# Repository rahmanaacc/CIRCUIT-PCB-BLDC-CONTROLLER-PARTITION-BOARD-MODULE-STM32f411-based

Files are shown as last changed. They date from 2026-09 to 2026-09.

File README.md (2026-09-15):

# Modular BLDC Motor Controller Partition Board (STM32F411CEU6 Based)

Projek Capstone ini berfokus pada perancangan hardware modul *controller* motor BLDC (Brushless DC) berbasis mikrokontroler **STM32F411CEU6** menggunakan metode kontrol **6-step commutation (trapezoidal control)**. 

Arsitektur hardware dirancang secara modular (*partition board*) dengan memisahkan domain sinyal kendali, *gate driver*, dan tingkat daya (*inverter stage*). Pemisahan topologi ini bertujuan untuk meminimalkan *noise* switching (EMI), mengoptimalkan manajemen termal, serta mempermudah proses pengujian dan *troubleshooting* secara independen pada tiap modul.

---

## Modul Hardware Utama

Repository ini terdiri dari tiga modul papan terpisah (*partition boards*):

1. **Control-MCU Module (`Control-MCU With Voltage Drop Detector 0,5mm`)**
   * Modul pemroses utama berbasis mikrokontroler **STM32F411CEU6**.
   * Dilengkapi rangkaian *Voltage Drop Detector* dengan lebar jalur *trace* teroptimasi 0,5 mm untuk menjaga integritas sinyal dan stabilitas tegangan referensi MCU.
   * Berfungsi mengolah algoritma **6-step commutation**, membaca sinyal *feedback* posisi rotor, dan menghasilkan sinyal PWM transmisi ke *gate driver*.

2. **Driver & Switching Optimization Circuit (`DRIVER and SWITCHING OPTIMIZATION CIRCUIT REV 2`)**
   * Modul perantara *gate driver* yang mengisolasi sinyal logika kendali level rendah dari tegangan tinggi *inverter*.
   * Mengintegrasikan rangkaian optimasi *switching* untuk mempercepat *rise/fall time* MOSFET, mengurangi *switching loss*, dan mencegah kondisi *cross-conduction* (*shoot-through*).

3. **Inverter Circuit (`INVERTER CIRCUIT REV 2 FIX`)**
   * Modul tingkat daya (*power stage*) berupa jembatan tiga fasa (*three-phase bridge inverter*).
   * Didesain untuk menangani arus tinggi dengan penataan jalur *copper pour* teroptimasi dan konektivitas daya fasa motor yang andal.

---

## Struktur Repository

```text
CIRCUIT-PCB-BLDC-CONTROLLER-PARTITION-BOARD-MODULE-STM32f411-based/
│
├── Control-MCU With Voltage Drop Detector 0,5mm/
│   ├── Control-MCU.kicad_sch          # Skematik KiCad Modul MCU
│   ├── Control-MCU.kicad_pcb          # Layout PCB Modul MCU
│   └── Control-MCU.kicad_pro          # Berkas Proyek KiCad Modul MCU
│
├── DRIVER and SWITCHING OPTIMIZATION CIRCUIT REV 2/
│   ├── DRIVER and SWITCHING OPTIMIZATION CIRCUIT.kicad_sch
│   ├── DRIVER and SWITCHING OPTIMIZATION CIRCUIT.kicad_pcb
│   └── DRIVER and SWITCHING OPTIMIZATION CIRCUIT.kicad_pro
│
├── INVERTER CIRCUIT REV 2 FIX/
│   ├── INVERTER CIRCUIT REV 2 FIX.kicad_sch
│   ├── INVERTER CIRCUIT REV 2 FIX.kicad_pcb
│   └── INVERTER CIRCUIT REV 2 FIX.kicad_pro
│
└── README.md

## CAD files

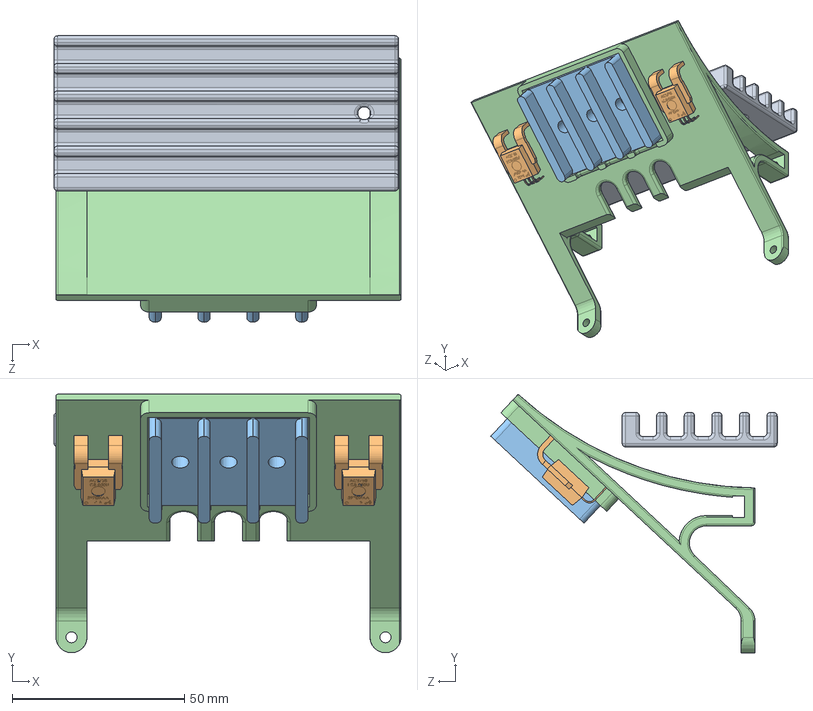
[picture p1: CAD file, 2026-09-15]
INVERTER CIRCUIT REV 2 FIX/mount current sensor.SLDASM
100.7 x 75.0 x 83.1 mm
E bike Connector
ACS758.step x 2
Part1^heatsink

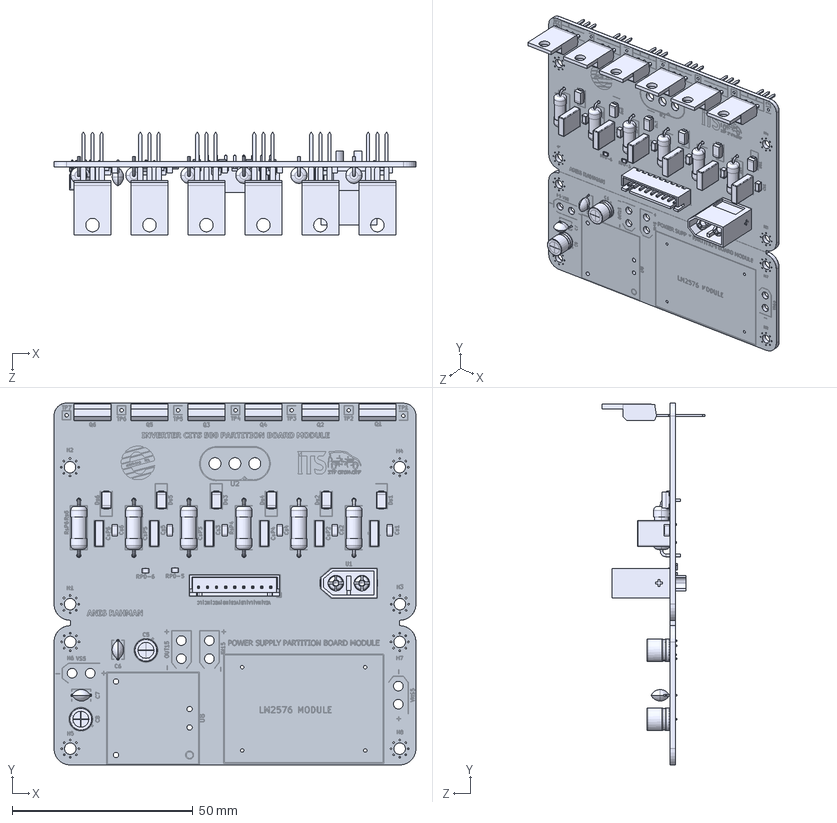
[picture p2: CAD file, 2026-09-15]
INVERTER CIRCUIT REV 2 FIX/INVERTER CIRCUIT REV 2 FIX 2.STEP
100.0 x 100.0 x 28.5 mm
C_Rect_L7.2mm_W2.5mm_P5.00mm_FKS2_FKP2_MKS2_MKP2.step x 6
D_SMA.step x 6
R_1206_3216Metric.step x 6
CP_Radial_D6.3mm_P2.50mm.step x 2
C_1206_3216Metric.step x 6
TO-220-3_Vertical.step x 6
R_Axial_DIN0414_L11.9mm_D4.5mm_P15.24mm_Horizontal.step x 6
C_Disc_D5.1mm_W3.2mm_P5.00mm.step x 2
JST_XH_B9B-XH-A_1x09_P2.50mm_Vertical.step
R_0805_2012Metric.step x 6
INVERTER CIRCUIT REV 2 FIX_soldermask.step
AMASS_XT60-M_1x02_P7.2mm_Vertical.step
INVERTER CIRCUIT REV 2 FIX_silkscreen.step
INVERTER CIRCUIT REV 2 FIX_silkscreen-0.step
INVERTER CIRCUIT REV 2 FIX_soldermask-1.step
INVERTER CIRCUIT REV 2 FIX_PCB.step

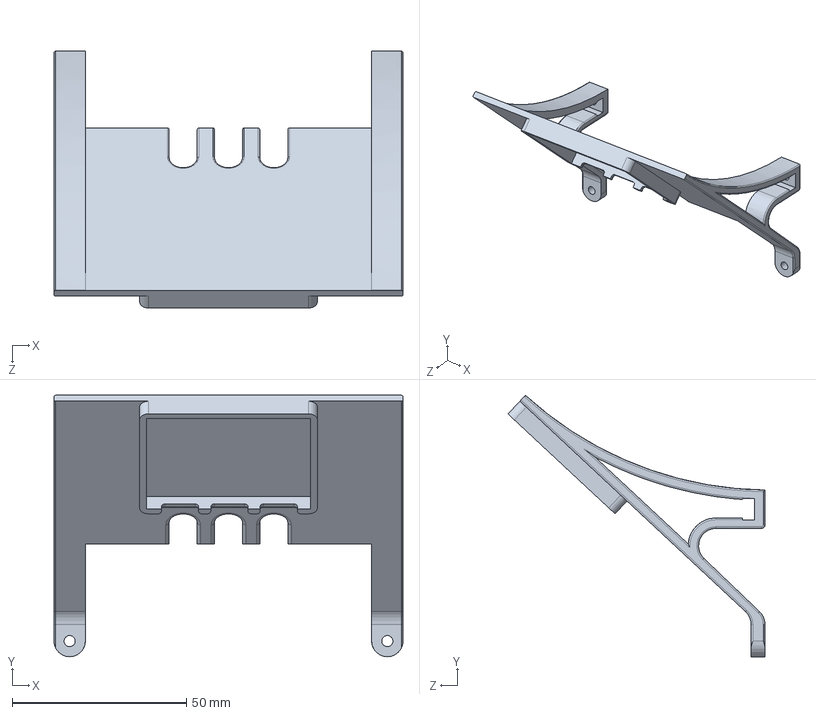
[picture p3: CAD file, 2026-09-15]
INVERTER CIRCUIT REV 2 FIX/Part1.SLDPRT
100.1 x 75.0 x 73.7 mm

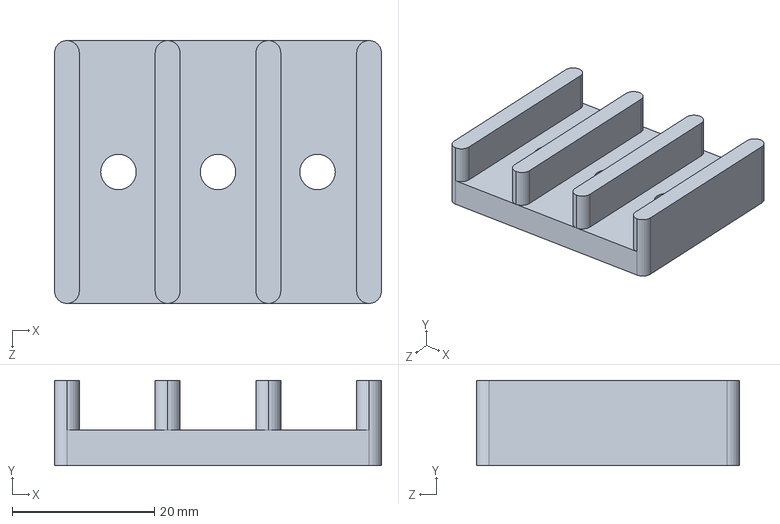
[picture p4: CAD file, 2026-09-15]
INVERTER CIRCUIT REV 2 FIX/E bike Connector.SLDPRT
46.0 x 12.0 x 37.0 mm

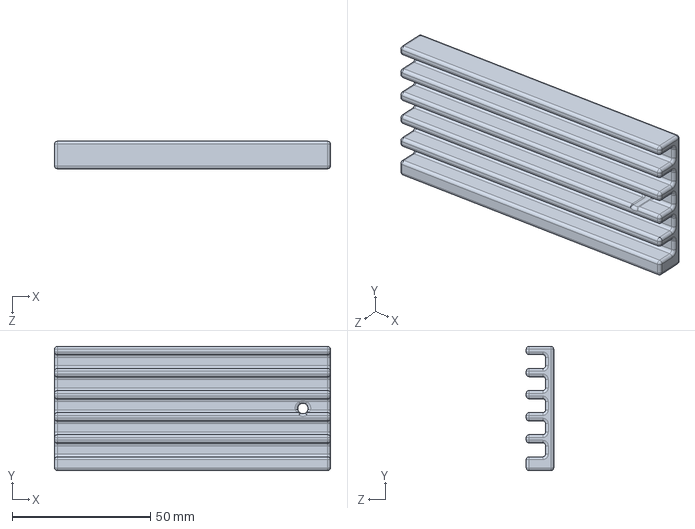
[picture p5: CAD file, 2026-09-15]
INVERTER CIRCUIT REV 2 FIX/Part1^heatsink.SLDPRT
100.0 x 45.0 x 10.0 mm

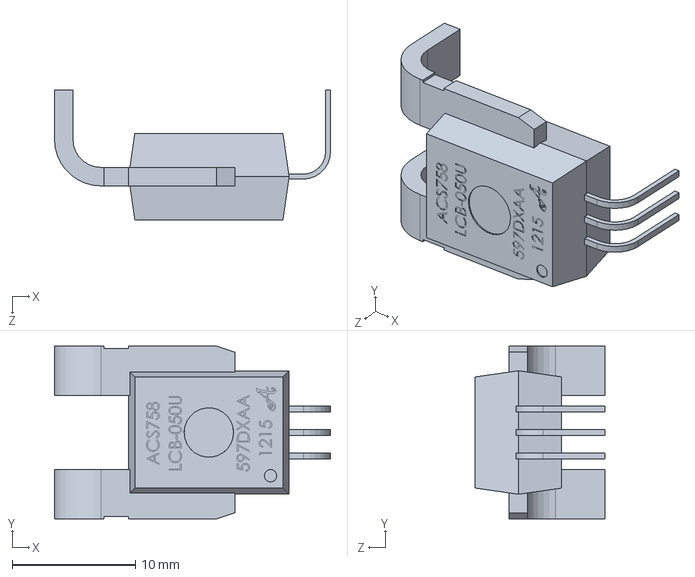
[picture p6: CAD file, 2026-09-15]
INVERTER CIRCUIT REV 2 FIX/ACS758.step.SLDPRT
22.4 x 14.0 x 10.5 mm

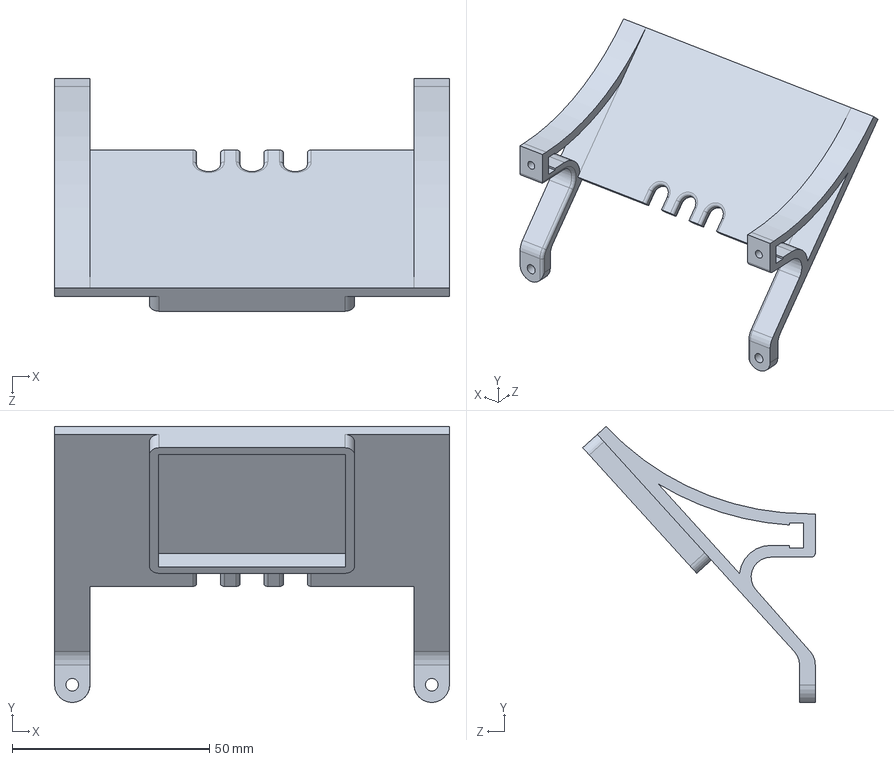
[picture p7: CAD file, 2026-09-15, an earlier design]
INVERTER CIRCUIT REV 2 FIX/Part1 - Copy.SLDPRT
100.1 x 69.9 x 58.9 mm

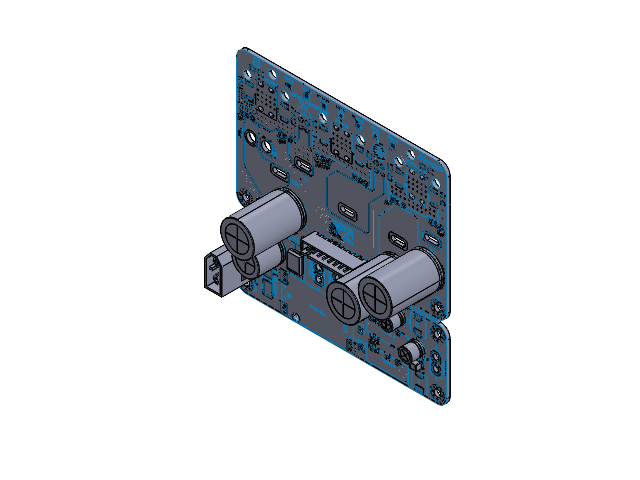
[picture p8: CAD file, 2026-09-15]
INVERTER CIRCUIT REV 2 FIX/INVERTER PARTITION BOARD REV4 STP FINAL CETAK solid.SLDASM
C_Radial_D16.0mm_H25.0mm_P7.50mm.step.STEP x 3
C_0805_2012Metric.step.STEP x 3
R_0603_1608Metric.step.STEP x 6
CP_Radial_D6.3mm_P2.50mm.step.STEP x 2
JST_XH_B9B-XH-A_1x09_P2.50mm_Vertical.step.STEP
AMASS_XT60-M_1x02_P7.2mm_Vertical.step.STEP
D_SMC.step.STEP
C_1210_3225Metric.step.STEP
CP_Radial_D13.0mm_P5.00mm.step.STEP
INVERTER PARTITION BOARD REV3_copper.step.STEP
INVERTER PARTITION BOARD REV3_silkscreen.step.STEP
INVERTER PARTITION BOARD REV3_silkscreen-0.step.STEP
INVERTER PARTITION BOARD REV3_soldermask.step.STEP
INVERTER PARTITION BOARD REV3_soldermask-1.step.STEP
INVERTER PARTITION BOARD REV3_PCB.step.STEP

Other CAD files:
INVERTER CIRCUIT REV 2 FIX/DUDUKAN TERMINAL 3 Phasaa BLDC Motor.STL
INVERTER CIRCUIT REV 2 FIX/INVERTER CIRCUIT REV 2 FIX.step
INVERTER CIRCUIT REV 2 FIX/INVERTER CIRCUIT REV 2 FIX.SLDPRT

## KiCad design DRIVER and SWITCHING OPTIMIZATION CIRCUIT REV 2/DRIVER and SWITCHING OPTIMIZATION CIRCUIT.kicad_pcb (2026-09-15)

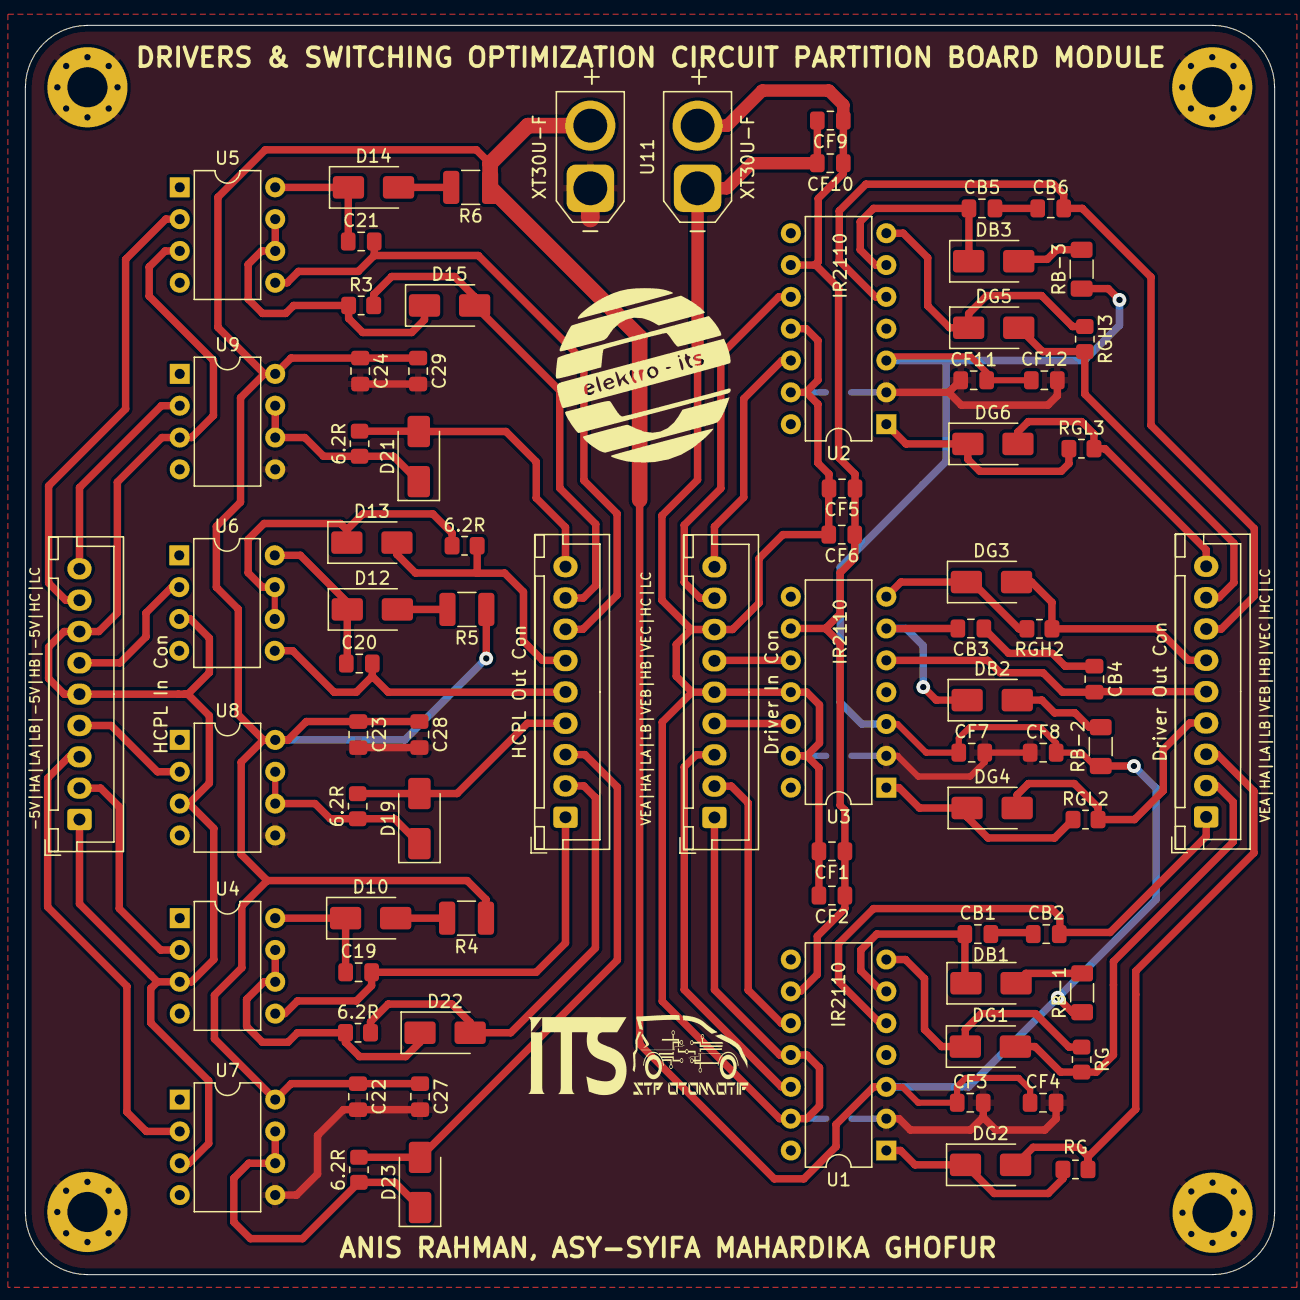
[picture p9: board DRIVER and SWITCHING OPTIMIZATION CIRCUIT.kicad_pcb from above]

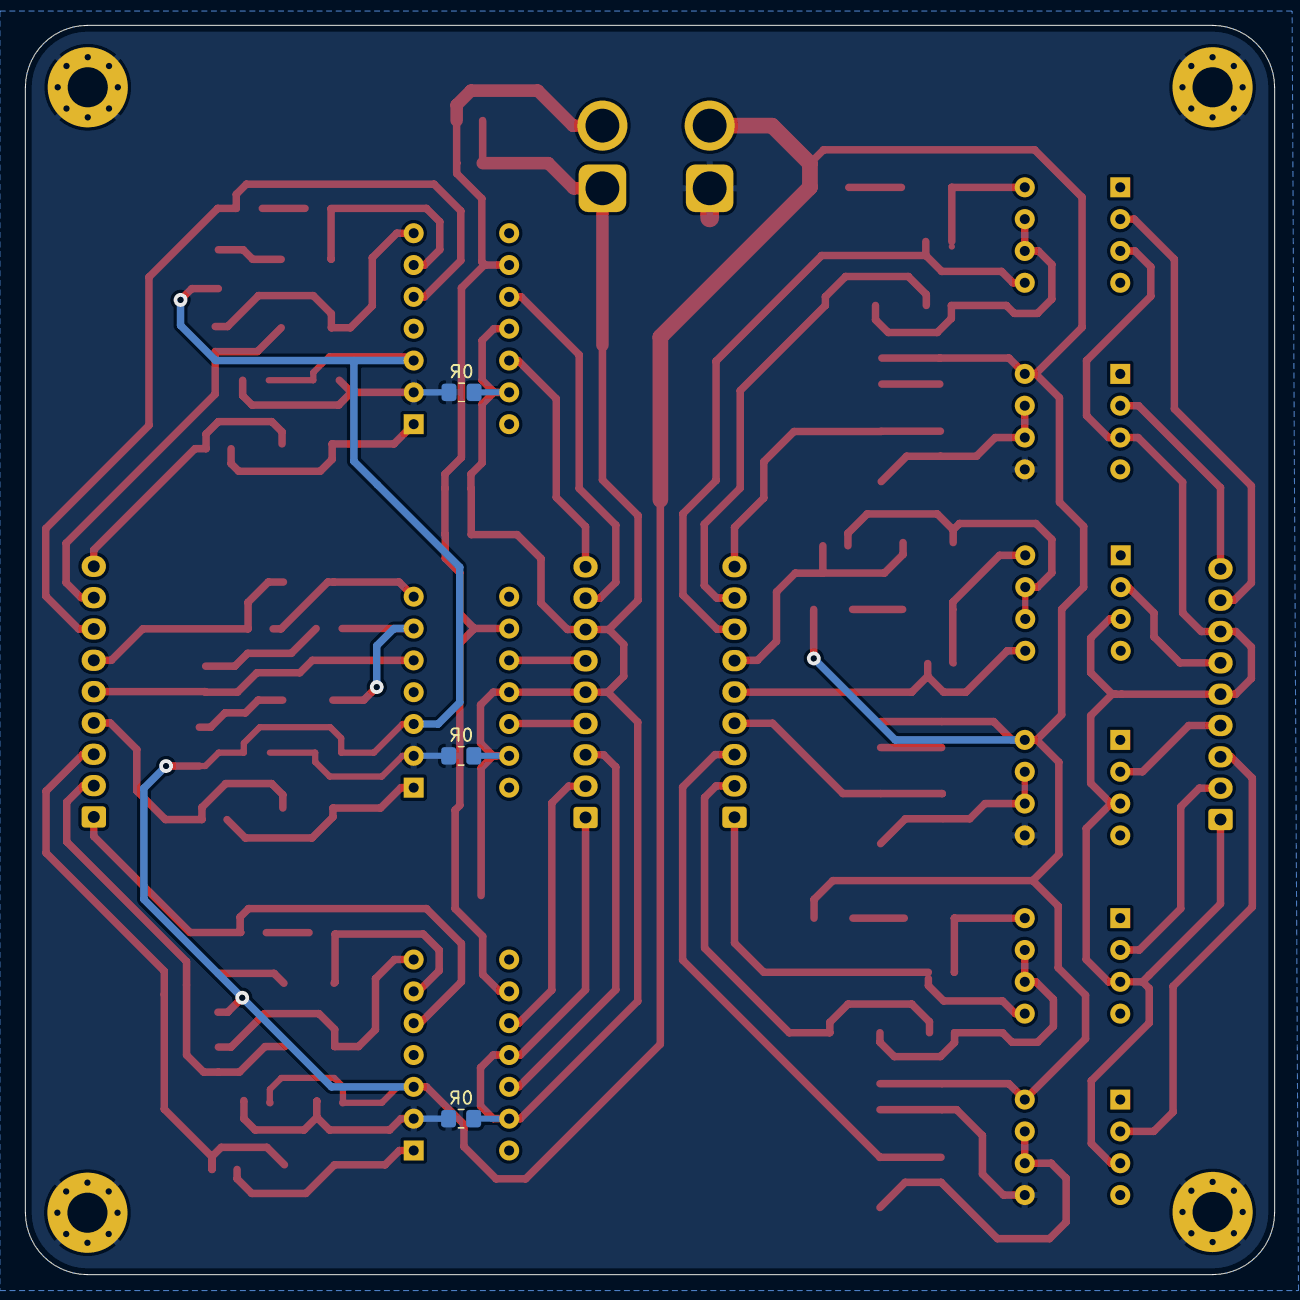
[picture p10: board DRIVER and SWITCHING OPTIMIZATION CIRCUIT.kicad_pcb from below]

Board: 2 copper layers, 99.7 x 99.7 mm, 85 parts (3 on the bottom side), 62 nets.

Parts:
C19, C20, C21: 0,22uF; C_0805_2012Metric_Pad1.18x1.45mm_HandSolder
C22, C23, C24: 0,1uF; C_0805_2012Metric_Pad1.18x1.45mm_HandSolder
C27, C28, C29: 10uF; C_0805_2012Metric_Pad1.18x1.45mm_HandSolder
CB1, CB2, CB3, CB4, CB5, CB6: 330nF; C_0805_2012Metric_Pad1.18x1.45mm_HandSolder
CF1, CF4, CF5, CF8, CF9, CF12: 10 uF; C_0805_2012Metric_Pad1.18x1.45mm_HandSolder
CF2, CF3, CF6, CF7, CF10, CF11: 0,1 uF; C_0805_2012Metric_Pad1.18x1.45mm_HandSolder
D10, D12, D13, D14, D15, D19, D21, D22, D23: SS110; D_SMA
DB1, DB2, DB3: SS110; D_SMA
DG1, DG2, DG3, DG4, DG5, DG6: SS110; D_SMA
H1, H2, H3, H4: MountingHole_Pad_MP1; MountingHole_3.2mm_M3_Pad_Via
J1: HCPL In Con; JST_XH_B9B-XH-A_1x09_P2.50mm_Vertical
J2: HCPL Out Con; JST_XH_B9B-XH-A_1x09_P2.50mm_Vertical
J3: Driver In Con; JST_XH_B9B-XH-A_1x09_P2.50mm_Vertical
J4: Driver Out Con; JST_XH_B9B-XH-A_1x09_P2.50mm_Vertical
R0J-1, R0J-2, R0J-3: 0R; R_0805_2012Metric_Pad1.20x1.40mm_HandSolder
R1, R2, R3, R7, R8, R9: 6.2R; R_0805_2012Metric_Pad1.20x1.40mm_HandSolder
R4, R5, R6: 3R; R_1210_3225Metric_Pad1.30x2.65mm_HandSolder
RB-1, RB-2, RB-3: 5,1R; R_1206_3216Metric_Pad1.30x1.75mm_HandSolder
RGH1, RGH2, RGH3: RG; R_0805_2012Metric_Pad1.20x1.40mm_HandSolder
RGL1, RGL2, RGL3: RG; R_0805_2012Metric_Pad1.20x1.40mm_HandSolder
U1, U2, U3: IR2110; DIP-14_W7.62mm
U4, U5, U6, U7, U8, U9: HCPL-3120; DIP-8_W7.62mm
U10, U11: XT30U-F; AMASS_XT30U-F_1x02_P5.0mm_Vertical

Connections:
5V_GND: CF1.2, CF2.2, CF5.2, CF6.2, CF9.2, CF10.2, J3.1, J3.5, J3.7, R0J-1.1, R0J-2.1, R0J-3.1, U1.11 (SD), U1.13 (VSS), U2.11 (SD), U2.13 (VSS), U3.11 (SD), U3.13 (VSS), U11.1 (-)
15V_GND: C22.2, C23.2, C24.2, C27.2, C28.2, C29.2, CF3.2, CF4.2, CF7.2, CF8.2, CF11.2, CF12.2, H1.1, H2.1 (MP), H3.1 (MP), H4.1 (MP), R0J-1.2, R0J-2.2, R0J-3.2, U1.2 (COM), U2.2 (COM), U3.2 (COM), U7.5 (VEE), U8.5 (VEE), U9.5 (VEE), U10.1 (-)
+5V: CF1.1, CF2.1, CF5.1, CF6.1, CF9.1, CF10.1, U1.9 (VDD), U2.9 (VDD), U3.9 (VDD), U11.2 (+)
+15V: C22.1, C23.1, C24.1, C27.1, C28.1, C29.1, CF3.1, CF4.1, CF7.1, CF8.1, CF11.1, CF12.1, R4.1, R5.1, R6.1, RB-1.1, RB-2.1, RB-3.1, U1.3 (VCC), U2.3 (VCC), U3.3 (VCC), U7.8 (VCC), U8.8 (VCC), U9.8 (VCC), U10.2 (+)
-5V: J1.1, J1.5, J1.7, U4.3 (C), U5.3 (C), U6.3 (C), U7.3 (C), U8.3 (C), U9.3 (C)
/HIN A: J1.2, U4.2 (A)
/HIN A DRIVER: J3.2, U1.10 (HIN)
/HIN A HCPL: D22.2 (A2), J2.2, R1.2
/HIN B: J1.6, U6.2 (A)
/HIN B DRIVER: J3.6, U3.10 (HIN)
/HIN B HCPL: D13.2 (A2), J2.6, R2.2
/HIN C: J1.8, U5.2 (A)
/HIN C DRIVER: J3.8, U2.10 (HIN)
/HIN C HCPL: D15.2 (A2), J2.8, R3.2
/High A Driver: DG1.2 (A2), J4.2, RGH1.2
/High B Driver: DG3.2 (A2), J4.6, RGH2.2
/High C Driver: DG5.2 (A2), J4.8, RGH3.2
/LIN A: J1.3, U7.2 (A)
/LIN A DRIVER: J3.3, U1.12 (LIN)
/LIN A HCPL: D23.2 (A2), J2.3, R7.2
/LIN B: J1.4, U8.2 (A)
/LIN B DRIVER: J3.4, U3.12 (LIN)
/LIN B HCPL: D19.2 (A2), J2.4, R8.2
/LIN C: J1.9, U9.2 (A)
/LIN C DRIVER: J3.9, U2.12 (LIN)
/LIN C HCPL: D21.2 (A2), J2.9, R9.2
/Low A Driver: DG2.2 (A2), J4.3, RGL1.2
/Low B Driver: DG4.2 (A2), J4.4, RGL2.2
/Low C Driver: DG6.2 (A2), J4.9, RGL3.2
/VEE A: C19.2, J2.1, U4.5 (VEE)
/VEE B: C20.2, J2.5, U6.5 (VEE)
/VEE C: C21.2, J2.7, U5.5 (VEE)
/VS A Driver: CB2.2, J4.1, U1.5 (VS)
/VS B Driver: CB4.2, J4.5, U3.5 (VS)
/VS C Driver: CB6.2, J4.7, U2.5 (VS)
unnamed: CB1.2, CB2.1
unnamed: CB3.2, CB4.1
unnamed: CB5.2, CB6.1
unnamed: C19.1, D10.1 (A1), U4.8 (VCC)
unnamed: D10.2 (A2), R4.2
unnamed: C20.1, D12.1 (A1), U6.8 (VCC)
unnamed: D12.2 (A2), R5.2
unnamed: D13.1 (A1), R2.1, U6.6 (VO), U6.7 (VO)
unnamed: C21.1, D14.1 (A1), U5.8 (VCC)
unnamed: D14.2 (A2), R6.2
unnamed: D15.1 (A1), R3.1, U5.6 (VO), U5.7 (VO)
unnamed: D19.1 (A1), R8.1, U8.6 (VO), U8.7 (VO)
unnamed: D21.1 (A1), R9.1, U9.6 (VO), U9.7 (VO)
unnamed: D22.1 (A1), R1.1, U4.6 (VO), U4.7 (VO)
unnamed: D23.1 (A1), R7.1, U7.6 (VO), U7.7 (VO)
unnamed: CB1.1, DB1.1 (A1), U1.6 (VB)
unnamed: DB1.2 (A2), RB-1.2
unnamed: CB3.1, DB2.1 (A1), U3.6 (VB)
unnamed: DB2.2 (A2), RB-2.2
unnamed: CB5.1, DB3.1 (A1), U2.6 (VB)
unnamed: DB3.2 (A2), RB-3.2
unnamed: DG1.1 (A1), RGH1.1, U1.7 (HO)
unnamed: DG2.1 (A1), RGL1.1, U1.1 (LO)
unnamed: DG3.1 (A1), RGH2.1, U3.7 (HO)
unnamed: DG4.1 (A1), RGL2.1, U3.1 (LO)
unnamed: DG5.1 (A1), RGH3.1, U2.7 (HO)
unnamed: DG6.1 (A1), RGL3.1, U2.1 (LO)

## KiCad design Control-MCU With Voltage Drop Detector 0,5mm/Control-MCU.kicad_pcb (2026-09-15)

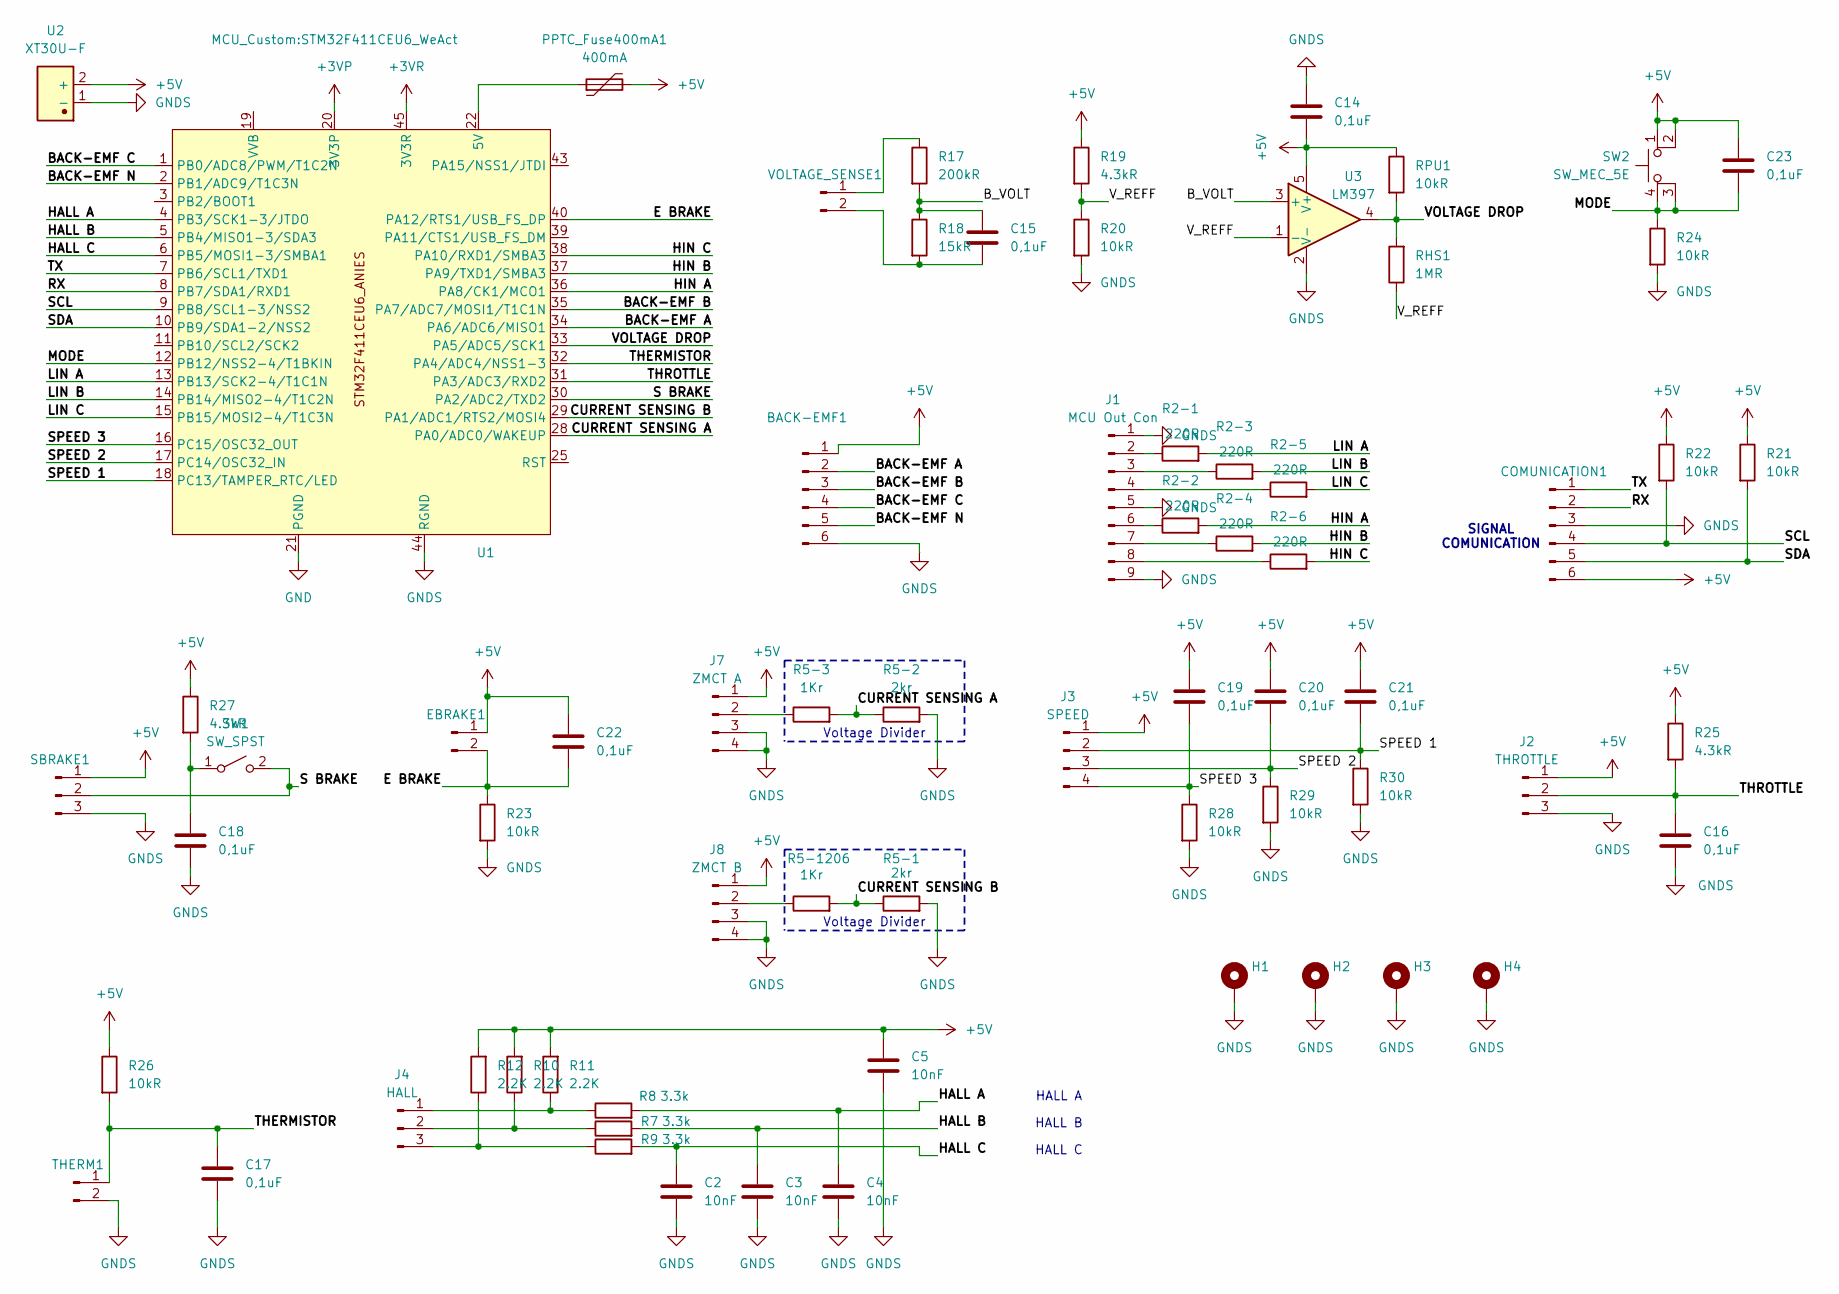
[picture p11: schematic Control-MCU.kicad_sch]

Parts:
BACK-EMF1: Conn_01x06_Pin; JST_XH_B6B-XH-A_1x06_P2.50mm_Vertical
C2, C3, C4, C5: 10nF; C_1206_3216Metric_Pad1.33x1.80mm_HandSolder
C14, C15, C16, C17, C18, C19, C20, C21, C22, C23: 0,1uF; C_0805_2012Metric_Pad1.18x1.45mm_HandSolder
COMUNICATION1: Conn_01x06_Pin; JST_XH_B6B-XH-A_1x06_P2.50mm_Vertical
EBRAKE1: EBRAKE; JST_XH_B2B-XH-A_1x02_P2.50mm_Vertical
H1, H2, H3, H4: MountingHole_Pad_MP1; MountingHole_3.2mm_M3_Pad_Via
J1: MCU Out Con; JST_XH_B9B-XH-A_1x09_P2.50mm_Vertical
J2: THROTTLE; JST_XH_B3B-XH-A_1x03_P2.50mm_Vertical
J3: SPEED; JST_XH_B4B-XH-A_1x04_P2.50mm_Vertical
J4: HALL; JST_XH_B3B-XH-A_1x03_P2.50mm_Vertical
J7: ZMCT A; JST_XH_B4B-XH-A_1x04_P2.50mm_Vertical
J8: ZMCT B; JST_XH_B4B-XH-A_1x04_P2.50mm_Vertical
PPTC_Fuse400mA1: 400mA; Fuse_1206_3216Metric_Pad1.42x1.75mm_HandSolder
R2-1, R2-2, R2-3, R2-4, R2-5, R2-6: 220R; R_0805_2012Metric_Pad1.20x1.40mm_HandSolder
R5-1, R5-2: 2kr; R_1206_3216Metric_Pad1.30x1.75mm_HandSolder
R5-3, R5-1206: 1Kr; R_1206_3216Metric_Pad1.30x1.75mm_HandSolder
R7, R8, R9: 3.3k; R_0603_1608Metric_Pad0.98x0.95mm_HandSolder
R10, R11, R12: 2.2K; R_0603_1608Metric_Pad0.98x0.95mm_HandSolder
R17: 200kR; R_0805_2012Metric_Pad1.20x1.40mm_HandSolder
R18: 15kR; R_0805_2012Metric_Pad1.20x1.40mm_HandSolder
R19, R25, R27: 4.3kR; R_0805_2012Metric_Pad1.20x1.40mm_HandSolder
R20, R21, R22, R23, R24, R26, R28, R29, R30: 10kR; R_0805_2012Metric_Pad1.20x1.40mm_HandSolder
RHS1: 1MR; R_0805_2012Metric_Pad1.20x1.40mm_HandSolder
RPU1: 10kR; R_0805_2012Metric_Pad1.20x1.40mm_HandSolder
SBRAKE1: BRAKE; JST_XH_B3B-XH-A_1x03_P2.50mm_Vertical
SW1: SW_SPST; SW_DIP_SPSTx01_Slide_6.7x4.1mm_W7.62mm_P2.54mm_LowProfile
SW2: SW_MEC_5E; SW_PUSH_6mm_H5mm
THERM1: Conn_01x02_Pin; JST_XH_B2B-XH-A_1x02_P2.50mm_Vertical
U1: STM32F411CEU6_WeAct
U2: XT30U-F; AMASS_XT30U-F_1x02_P5.0mm_Vertical; Manufacturer Part XT30U-F
U3: LM397; SOT-23-5
VOLTAGE_SENSE1: VOLTAGE_SENSE; JST_XH_B2B-XH-A_1x02_P2.50mm_Vertical

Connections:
+3VP: U1.20 (3V3P)
+3VR: U1.45 (3V3R)
+5V: BACK-EMF1.1, C5.1, C14.2, C19.1, C20.1, C21.1, C22.1, C23.1, COMUNICATION1.6, EBRAKE1.1, J2.1, J3.1, J7.1, J8.1, PPTC_Fuse400mA1.2, R10.2, R11.2, R12.2, R19.1, R21.1, R22.1, R25.1, R26.1, R27.1, RPU1.1, SBRAKE1.1, SW2.1, SW2.2, U2.2 (+), U3.5 (V+)
/BACK-EMF A: BACK-EMF1.2, U1.34 (PA6/ADC6/MISO1)
/BACK-EMF B: BACK-EMF1.3, U1.35 (PA7/ADC7/MOSI1/T1C1N)
/BACK-EMF C: BACK-EMF1.4, U1.1 (PB0/ADC8/PWM/T1C2N)
/BACK-EMF N: BACK-EMF1.5, U1.2 (PB1/ADC9/T1C3N)
/B_VOLT: C15.1, R17.2, R18.1, U3.3 (+)
/CURRENT SENSING A: R5-2.1, R5-3.2, U1.28 (PA0/ADC0/WAKEUP)
/CURRENT SENSING B: R5-1.1, R5-1206.2, U1.29 (PA1/ADC1/RTS2/MOSI4)
/E BRAKE: C22.2, EBRAKE1.2, R23.1, U1.40 (PA12/RTS1/USB_FS_DP)
/HALL A: C4.1, R8.2, U1.4 (PB3/SCK1-3/JTDO)
/HALL B: C3.1, R7.2, U1.5 (PB4/MISO1-3/SDA3)
/HALL C: C2.1, R9.2, U1.6 (PB5/MOSI1-3/SMBA1)
/HIN A: R2-2.2, U1.36 (PA8/CK1/MCO1)
/HIN B: R2-4.2, U1.37 (PA9/TXD1/SMBA3)
/HIN C: R2-6.2, U1.38 (PA10/RXD1/SMBA3)
/LIN A: R2-1.2, U1.13 (PB13/SCK2-4/T1C1N)
/LIN B: R2-3.2, U1.14 (PB14/MISO2-4/T1C2N)
/LIN C: R2-5.2, U1.15 (PB15/MOSI2-4/T1C3N)
/MODE: C23.2, R24.1, SW2.3 (K), SW2.4 (A), U1.12 (PB12/NSS2-4/T1BKIN)
/RX: COMUNICATION1.2, U1.8 (PB7/SDA1/RXD1)
/S BRAKE: SBRAKE1.2, SW1.2 (B), U1.30 (PA2/ADC2/TXD2)
/SCL: COMUNICATION1.4, R22.2, U1.9 (PB8/SCL1-3/NSS2)
/SDA: COMUNICATION1.5, R21.2, U1.10 (PB9/SDA1-2/NSS2)
/SPEED 1: C21.2, J3.2, R30.1, U1.18 (PC13/TAMPER_RTC/LED)
/SPEED 2: C20.2, J3.3, R29.1, U1.17 (PC14/OSC32_IN)
/SPEED 3: C19.2, J3.4, R28.1, U1.16 (PC15/OSC32_OUT)
/THERMISTOR: C17.1, R26.2, THERM1.1, U1.32 (PA4/ADC4/NSS1-3)
/THROTTLE: C16.1, J2.2, R25.2, U1.31 (PA3/ADC3/RXD2)
/TX: COMUNICATION1.1, U1.7 (PB6/SCL1/TXD1)
/VOLTAGE DROP: RHS1.2, RPU1.2, U1.33 (PA5/ADC5/SCK1), U3.4
/V_REFF: R19.2, R20.1, RHS1.1, U3.1 (-)
GND: U1.21 (PGND)
GNDS: BACK-EMF1.6, C2.2, C3.2, C4.2, C5.2, C14.1, C16.2, C17.2, C18.2, COMUNICATION1.3, H1.1, H2.1, H3.1, H4.1, J1.1, J1.5, J1.9, J2.3, J7.3, J7.4, J8.3, J8.4, R5-1.2, R5-2.2, R20.2, R23.2, R24.2, R28.2, R29.2, R30.2, SBRAKE1.3, THERM1.2, U1.44 (RGND), U2.1 (-), U3.2 (V-)
unnamed: J1.2, R2-1.1
unnamed: J1.3, R2-3.1
unnamed: J1.4, R2-5.1
unnamed: J1.6, R2-2.1
unnamed: J1.7, R2-4.1
unnamed: J1.8, R2-6.1
unnamed: J4.1, R8.1, R11.1
unnamed: J4.2, R7.1, R10.1
unnamed: J4.3, R9.1, R12.1
unnamed: J7.2, R5-3.1
unnamed: J8.2, R5-1206.1
unnamed: C18.1, R27.2, SW1.1 (A)
unnamed: PPTC_Fuse400mA1.1, U1.22 (5V)
unnamed: R17.1, VOLTAGE_SENSE1.1
unnamed: C15.2, R18.2, VOLTAGE_SENSE1.2

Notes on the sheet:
Voltage Divider
HALL C
HALL A
HALL B
SIGNAL COMUNICATION

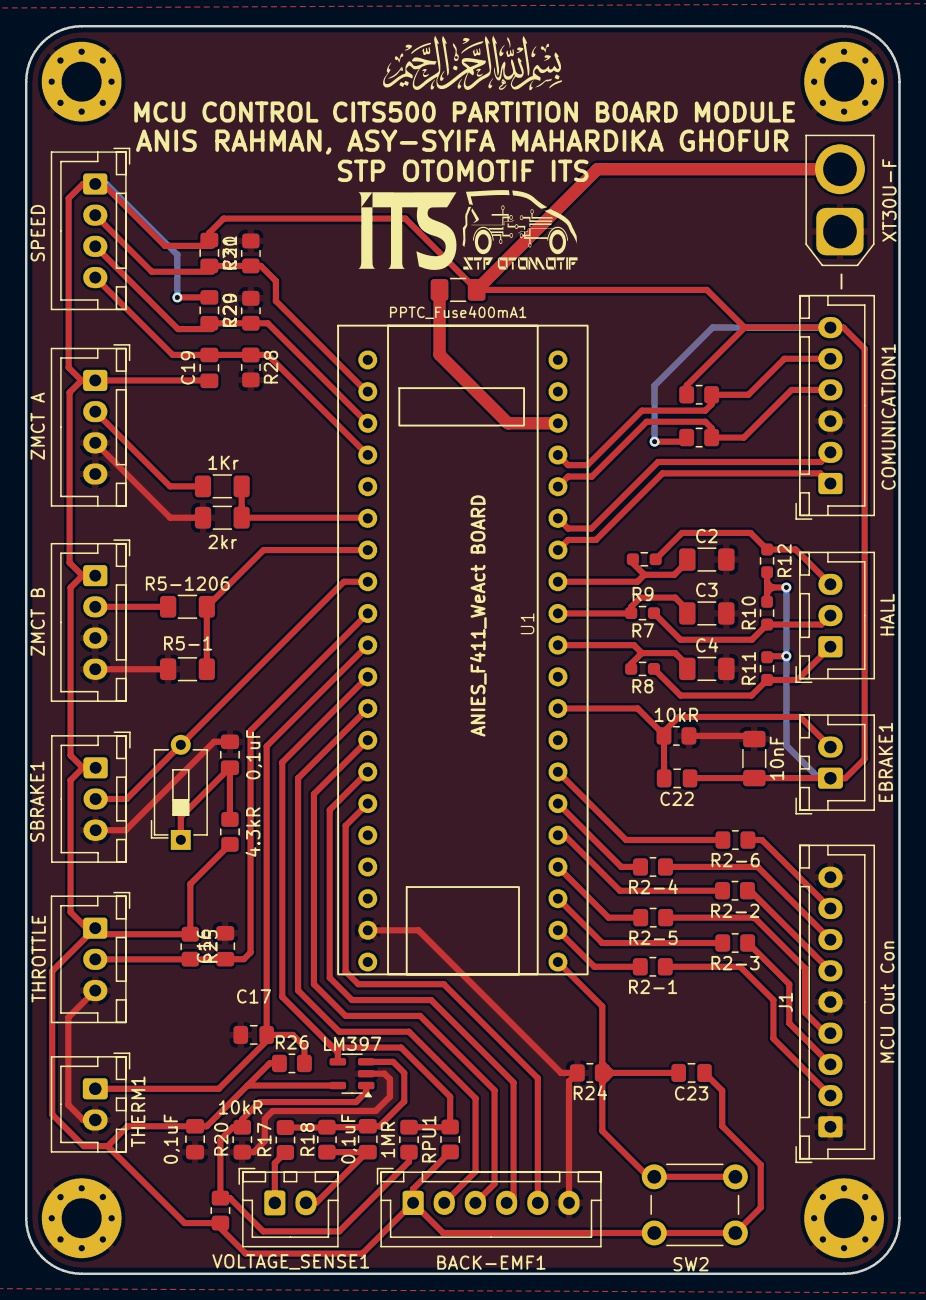
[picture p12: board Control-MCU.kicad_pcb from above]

Board: 2 copper layers, 70.0 x 100.0 mm, 68 parts (0 on the bottom side), 47 nets.

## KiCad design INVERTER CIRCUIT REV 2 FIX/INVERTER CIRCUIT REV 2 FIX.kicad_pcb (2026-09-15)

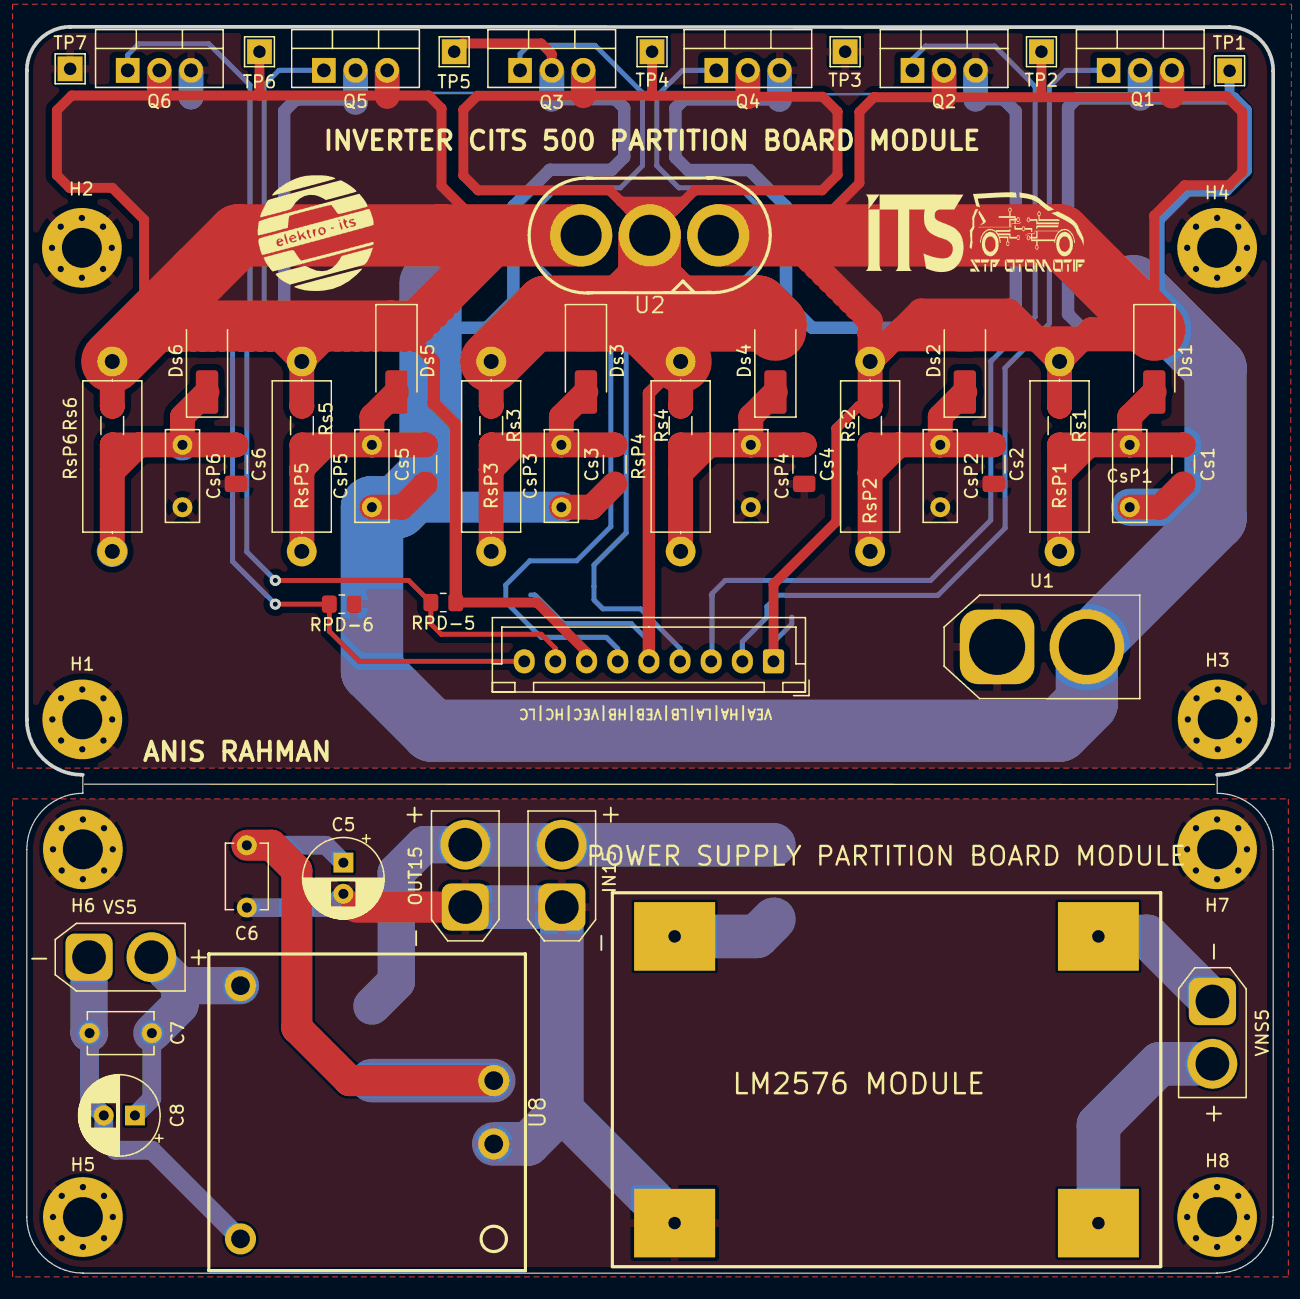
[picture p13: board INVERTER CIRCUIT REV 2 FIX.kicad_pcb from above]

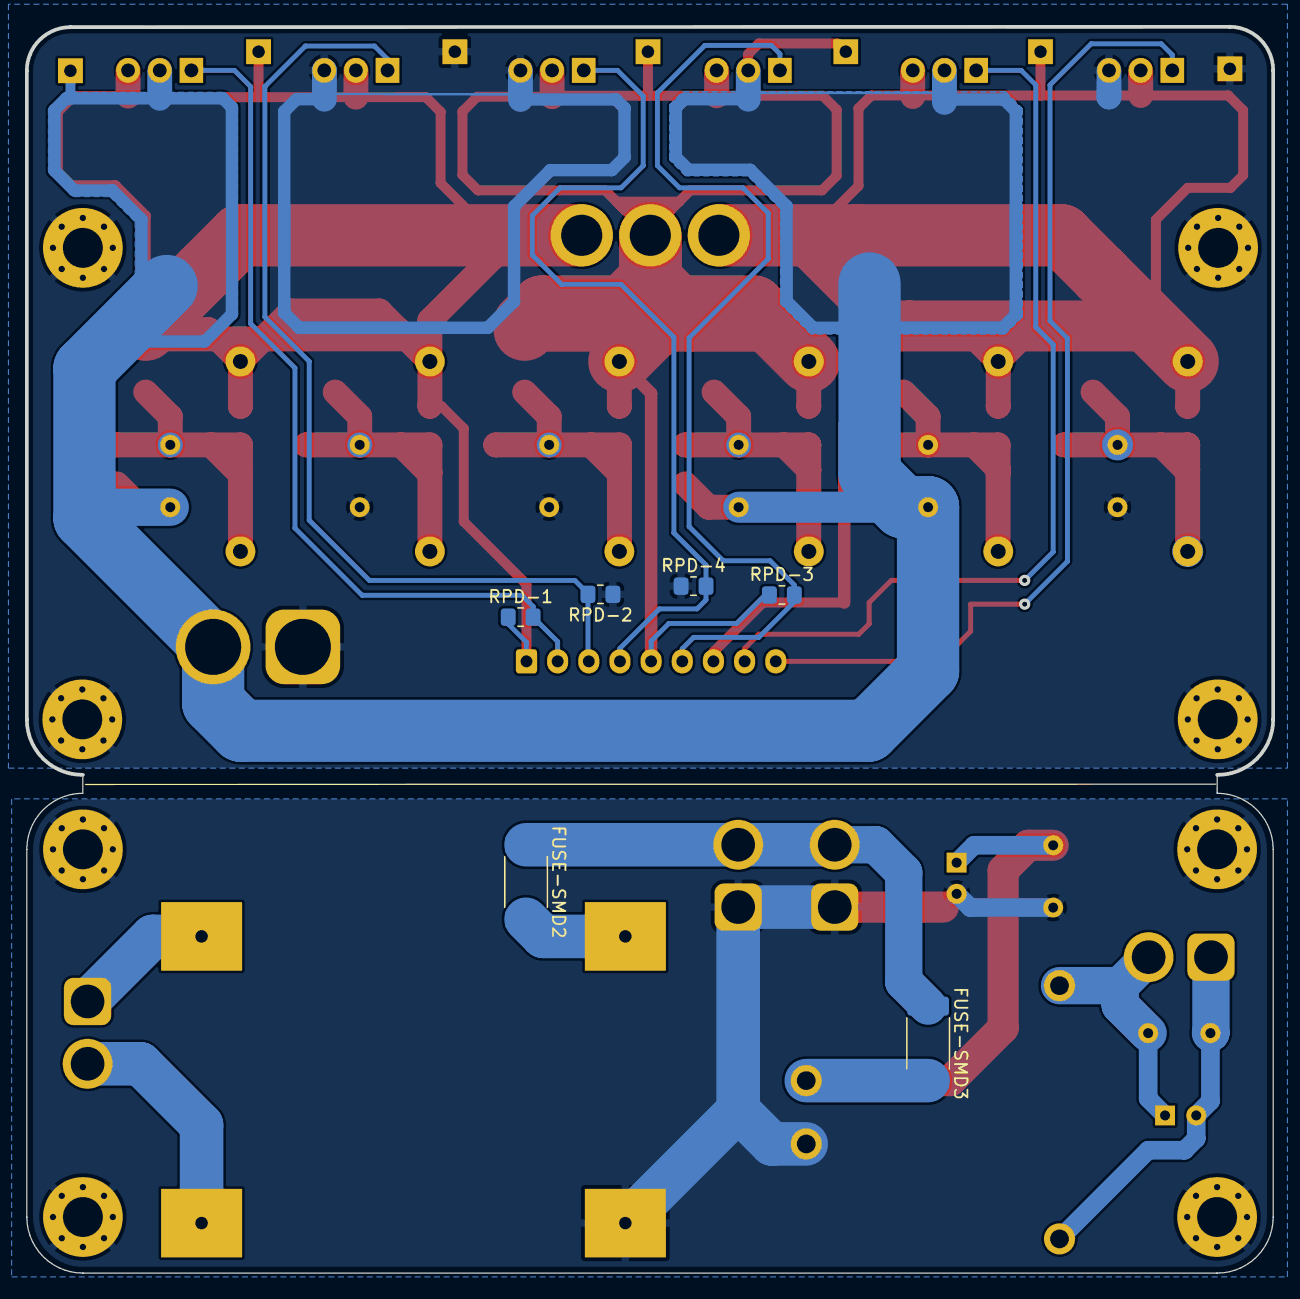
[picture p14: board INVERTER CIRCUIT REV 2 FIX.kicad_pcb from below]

Board: 2 copper layers, 100.0 x 100.0 mm, 72 parts (6 on the bottom side), 25 nets.

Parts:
C5, C8: ELCO 220 uF; CP_Radial_D6.3mm_P2.50mm
C6, C7: CERAMIC 100 nF; C_Disc_D5.1mm_W3.2mm_P5.00mm
Cs1, Cs2, Cs3, Cs4, Cs5, Cs6: 4.7nF; C_1206_3216Metric_Pad1.33x1.80mm_HandSolder
CsP1, CsP2, CsP3, CsP4, CsP5, CsP6: 4.7nF; C_Rect_L7.2mm_W2.5mm_P5.00mm_FKS2_FKP2_MKS2_MKP2
Ds1, Ds2, Ds3, Ds4, Ds5, Ds6: SS110; D_SMA_Handsoldering
FUSE-SMD2, FUSE-SMD3: 5A; Fuse_2512_6332Metric_Pad1.52x3.35mm_HandSolder
H1, H2, H3, H4, H5, H6, H7, H8: MountingHole_Pad_MP1; MountingHole_3.2mm_M3_Pad_Via
IN15: XT30U-IN; AMASS_XT30U-F_1x02_P5.0mm_Vertical
J1: Inverter In Con; JST_XH_B9B-XH-A_1x09_P2.50mm_Vertical
MOD2: LM2576 MODULE
OUT15: XT30U-OUT; AMASS_XT30U-F_1x02_P5.0mm_Vertical
Q1, Q2, Q3, Q4, Q5, Q6: TK100E10N1,S1X(S; TO-220-3_Vertical
RPD-1, RPD-2, RPD-3, RPD-4, RPD-5, RPD-6: 10K; R_0805_2012Metric_Pad1.20x1.40mm_HandSolder
Rs1, Rs2, Rs3, Rs4, Rs5, Rs6: 3K; R_1206_3216Metric_Pad1.30x1.75mm_HandSolder
RsP1, RsP2, RsP3, RsP4, RsP5, RsP6: 3k3; R_Axial_DIN0414_L11.9mm_D4.5mm_P15.24mm_Horizontal
TP1, TP2, TP3, TP4, TP5, TP6, TP7: TestPoint; TestPoint_THTPad_2.0x2.0mm_Drill1.0mm
U1: XT60U-F; AMASS_XT60-M_1x02_P7.20mm_Vertical
U2: MR30航模插头3P公头; CONN-TH_3P_MR60PB-M
U8: VRB2405YMD-6WR3
VNS5: XT30U-OUTNS; AMASS_XT30U-F_1x02_P5.0mm_Vertical
VS5: XT30U-OUT; AMASS_XT30U-F_1x02_P5.0mm_Vertical

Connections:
/+5V: C7.1, C8.1, U8.3 (+VO), VS5.2 (+)
/+5V NS: MOD2.3 (OUT+), VNS5.2 (+)
/+V15: FUSE-SMD2.1, FUSE-SMD3.1, IN15.2 (+), OUT15.2 (+)
/+VBATT: Cs1.1, Cs3.1, Cs5.1, CsP1.1, CsP3.1, CsP5.1, Q1.2 (D), Q3.2 (D), Q5.2 (D), TP1.1, TP5.1, U1.2 (+)
/-5V: C7.2, C8.2, U8.5 (0V), VS5.1 (-)
/-5V NS: MOD2.4 (OUT-), VNS5.1 (-)
/-V15: C5.2, C6.2, H5.1, H6.1, H7.1, H8.1, IN15.1 (-), MOD2.2 (IN-), OUT15.1 (-), U8.1 (GND)
/-VBATT: Cs2.2, Cs4.2, Cs6.2, CsP2.2, CsP4.2, CsP6.2, H1.1, H2.1, H3.1, H4.1, Q2.3 (S), Q4.3 (S), Q6.3 (S), RPD-2.1, RPD-4.1, RPD-6.1, TP3.1, TP7.1, U1.1 (-)
/Gate High A: J1.2, Q1.1 (G), RPD-1.2
/Gate High B: J1.6, Q3.1 (G), RPD-3.2
/Gate High C: J1.8, Q5.1 (G), RPD-5.2
/Gate Low A: J1.3, Q2.1 (G), RPD-2.2
/Gate Low B: J1.4, Q4.1 (G), RPD-4.2
/Gate Low C: J1.9, Q6.1 (G), RPD-6.2
/PHASE A: Ds1.1 (K), Ds2.2 (A), J1.1, Q1.3 (S), Q2.2 (D), RPD-1.1, Rs1.1, Rs2.2, RsP1.1, RsP2.2, TP2.1, U2.1
/PHASE B: Ds3.1 (K), Ds4.2 (A), J1.5, Q3.3 (S), Q4.2 (D), RPD-3.1, Rs3.1, Rs4.2, RsP3.1, RsP4.2, TP4.1, U2.2
/PHASE C: Ds5.1 (K), Ds6.2 (A), J1.7, Q5.3 (S), Q6.2 (D), RPD-5.1, Rs5.1, Rs6.2, RsP5.1, RsP6.2, TP6.1, U2.3
unnamed: Cs1.2, CsP1.2, Ds1.2 (A), Rs1.2, RsP1.2
unnamed: Cs2.1, CsP2.1, Ds2.1 (K), Rs2.1, RsP2.1
unnamed: Cs3.2, CsP3.2, Ds3.2 (A), Rs3.2, RsP3.2
unnamed: Cs4.1, CsP4.1, Ds4.1 (K), Rs4.1, RsP4.1
unnamed: Cs5.2, CsP5.2, Ds5.2 (A), Rs5.2, RsP5.2
unnamed: Cs6.1, CsP6.1, Ds6.1 (K), Rs6.1, RsP6.1
unnamed: FUSE-SMD2.2, MOD2.1 (IN+)
unnamed: C5.1, C6.1, FUSE-SMD3.2, U8.2 (VIN)

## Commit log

2026-09-15 Initial commit: Add all BLDC controller partition board modules
    [ACS758.step.SLDPRT, Control-MCU.kicad_pcb, Control-MCU.kicad_sch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]
2026-09-15 Chore: exclude 3D CAD models and autosave files
    [ACS758.step.SLDPRT, DUDUKAN TERMINAL 3 Phasaa BLDC Motor.STL, E bike Connector.SLDPRT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]
2026-09-15 Feat: include all project files, 3D CAD models, and assemblies
    [ACS758.step.SLDPRT, DUDUKAN TERMINAL 3 Phasaa BLDC Motor.STL, E bike Connector.SLDPRT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]
2026-09-15 Feat: remove subfolder gitignore and track all files
    [Control-MCU-B_Cu.gbr, Control-MCU-B_Mask.gbr, Control-MCU-B_Paste.gbr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]
2026-09-15 Add project overview and repository structure to README
    Added detailed information about the modular BLDC motor controller project, including hardware modules and repository structure.
